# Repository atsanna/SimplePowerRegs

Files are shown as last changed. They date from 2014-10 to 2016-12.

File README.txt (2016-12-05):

This is the Simple Power series of switching regulators,
and its Open Source Hardware OSHW documentation.

They were designed in this order, making changes and improvements
along the way. pwrlnk.com has a blog with some discussion of the 
design process.

v1 
is 5V 3A output, with up to 30VDC input.
still useful for smaller loads.

v2 
changes the switcher part to 5 Amp output and adds a full-wave 
bridge at the input, up to 7-28VDC or 6-18VAC.

The same board supports two variations with a few parts changes:
1) 5Amp fixed 5VDC output.
2) 5Amp varible 1.2 ~ 15 VDC output.

v3 
is 5V 5A output, with 7-28VDC or 6-18VAC input.

v4 
is a refinement of v3, available at tindie.com

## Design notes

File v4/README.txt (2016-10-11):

v4:

This version is a refinement of v3, also fixed 5V with 2 USB charge ports. 

It has a 5.5mm/2.1mm barrel connector on the input, and pads for bare wires
up to 16 AWG on input and output.

The board is compatible with 1cmg.net, 48mm (1.89") square with 3.2mm (1/8") 
mounting holes on 40mm (1.575") centers, suitable for 4-40 or M3 screws.

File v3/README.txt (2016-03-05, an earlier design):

v3 was designed during the 1st Kickstarter campaign.

This version is 5V only, with 2 USB connectors.

The through hole manufacturing costs of the v2 full wave bridge 
part was troubling. So I made the bridge surface mount only by 
changing to 4 SMD schottky diodes. 

I also added a 26 V TVS diode to clip off any peaks in the input 
that get too close to the chip's 30 Volt absolute max rating.

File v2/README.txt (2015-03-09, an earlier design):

v2:
This is a one board, two products design with both 5 Volt and 
adjustable voltage output, up to 5 Amps. Only a few parts are 
different between the two models.

See http://pwrlnk.com/?q=node/6

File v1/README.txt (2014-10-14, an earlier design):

v1:
This is fixed 5V output up to 3 Amps. I used the design process 
in the TI data sheet, so my own value added here is in the 
board layout. The full ground plane acts as a heatsink, so no
external heat sink should be needed.

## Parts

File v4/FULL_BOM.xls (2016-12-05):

SMALL SYSTEMS LLC |  |  | MODEL 55
FIND | ID | Manufacturer | Mfg Part # | Description | Notes
1 | U1 | TI | TPS54531 | IC REG BUCK ADJ 5A 8SOPWRPAD | 3.5 ~ 28
2 | L1 | COOPER BUSSMAN | DR125-6R8-R | INDUCTOR SHIELD PWR 6.8UH SMD | 6.6A (8.7A sat)
3 | D1 | NXP | PMEG4050EP,115 | DIODE SCHOTTKY 40V 5A SOD128 | BRIDGE
 | D2 | NXP | PMEG4050EP,115 | DIODE SCHOTTKY 40V 5A SOD128 | BRIDGE
 | D3 | NXP | PMEG4050EP,115 | DIODE SCHOTTKY 40V 5A SOD128 | BRIDGE
 | D4 | NXP | PMEG4050EP,115 | DIODE SCHOTTKY 40V 5A SOD128 | BRIDGE
 | D6 | NXP | PMEG4050EP,115 | DIODE SCHOTTKY 40V 5A SOD128 | CATCH
4 | D5 | BOURNS | SMAJ26A | TVS 26 VOLTS | OVER-VOLT
5 | D7 | LITE-ON | LTST-C191KGKT | LED GREEN CLEAR 0603 SMD | PWR-ON
6 | C1 | Samsung | CL32B106KLJNNNE | CAP CER 10UF 35V 10% X7R 1210 | IN
 | C2 | Samsung | CL32B106KLJNNNE | CAP CER 10UF 35V 10% X7R 1210 | IN
7 | C3 | KEMET | C0805C103K5RACTU | CAP CER 10000PF 50V 10% X7R 0805 | IN
 | C4 | KEMET | C0805C103K5RACTU | CAP CER 10000PF 50V 10% X7R 0805 | BOOT
 | C7 | KEMET | C0805C103K5RACTU | CAP CER 10000PF 50V 10% X7R 0805 | SLOW
8 | C5 | AVX | 06035C220JAT2A | CAP CER 22PF 50V 5% X7R 0603 | COMP
9 | C6 | KEMET | C0805C222J5RACTU | CAP CER 2200PF 50V X7R 0805 | COMP
10 | C8 | Murata | GRM31CR61A476KE15L | CAP CER 47UF 10V 10% X5R 1206 | OUT
 | C9 | Murata | GRM31CR61A476KE15L | CAP CER 47UF 10V 10% X5R 1206 | OUT
11 | R1 | BOURNS | CR0603-JW-393GLF | RES SMD 39K OHM 5% 1/10W 0603 | COMP
12 | R2 | BOURNS | CR0603-FX-1202ELF | RES SMD 12K OHM 1% 1/10W 0603 | DIV-HI-5
13 | R3 | BOURNS | CR0603-FX-2211ELF | RES SMD 2.21K OHM 1% 1/10W 0603 | DIV-LO-5
15 | R4 | BOURNS | CR0603-JW-331GLF | RES SMD 330 OHM 5% 1/10W 0603 | PWR-ON
14 | R5 | BOURNS | CR0603-JW-101ELF | RES SMD 100 OHM 5% 1/10W 0603 | USB
 | R6 | BOURNS | CR0603-JW-101ELF | RES SMD 100 OHM 5% 1/10W 0603 | USB
NO-LOAD – optional connectors
16 | J1 | CUI | PJ-102AH | JACK MALE 2.1mm ID, 5.5mm OD | 5 Amp Hi Current
17 | J4 | FCI | 87520-0010BLF | CONN RCPT USB TYPE A R/A PCB | OUT
 | J5 | FCI | 87520-0010BLF | CONN RCPT USB TYPE A R/A PCB | OUT
18 | J2 | ON SHORE TECH | OSTTC022162 | TERM BLOCK 5.08MM VERT 2POS PCB | IN
 | J3 | ON SHORE TECH | OSTTC022162 | TERM BLOCK 5.08MM VERT 2POS PCB | OUT

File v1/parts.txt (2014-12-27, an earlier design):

DIGIKEY PART NUMBER	DESCRIPTION
-------------------	-----------

LM2676SX-5.0/NOPBCT-ND	IC REG BUCK 5V 3A TO263-7

513-1528-1-ND		INDUCTOR SHIELD PWR 33UH SMD
			COILTRONICS DR125-330-R

SK34A-LTPMSCT-ND	DIODE SCHOTTKY 40V 3A DO214AC
			MICRO COMMERCIAL SK34A-LTP

ED2609-ND		TERM BLOCK 5.08MM VERT 2POS PCB
			ON SHORE TECHNOLOGY OSTTC022162

399-3775-1-ND	C1	CAP TANT 15UF 35V 10% 2917
		C2	KEMET T.491.D.156.K.035.A.T

478-5231-1-ND	C3	CAP TANT 100UF 10V 20% 1210
		C4	AVX TPS.B.107.M.010.R.0400

399-1158-1-ND	C5	CAP CER 10000PF 50V 10% X7R 0805
							
609-1045-ND		USB 87520-0010BLF 2Amp

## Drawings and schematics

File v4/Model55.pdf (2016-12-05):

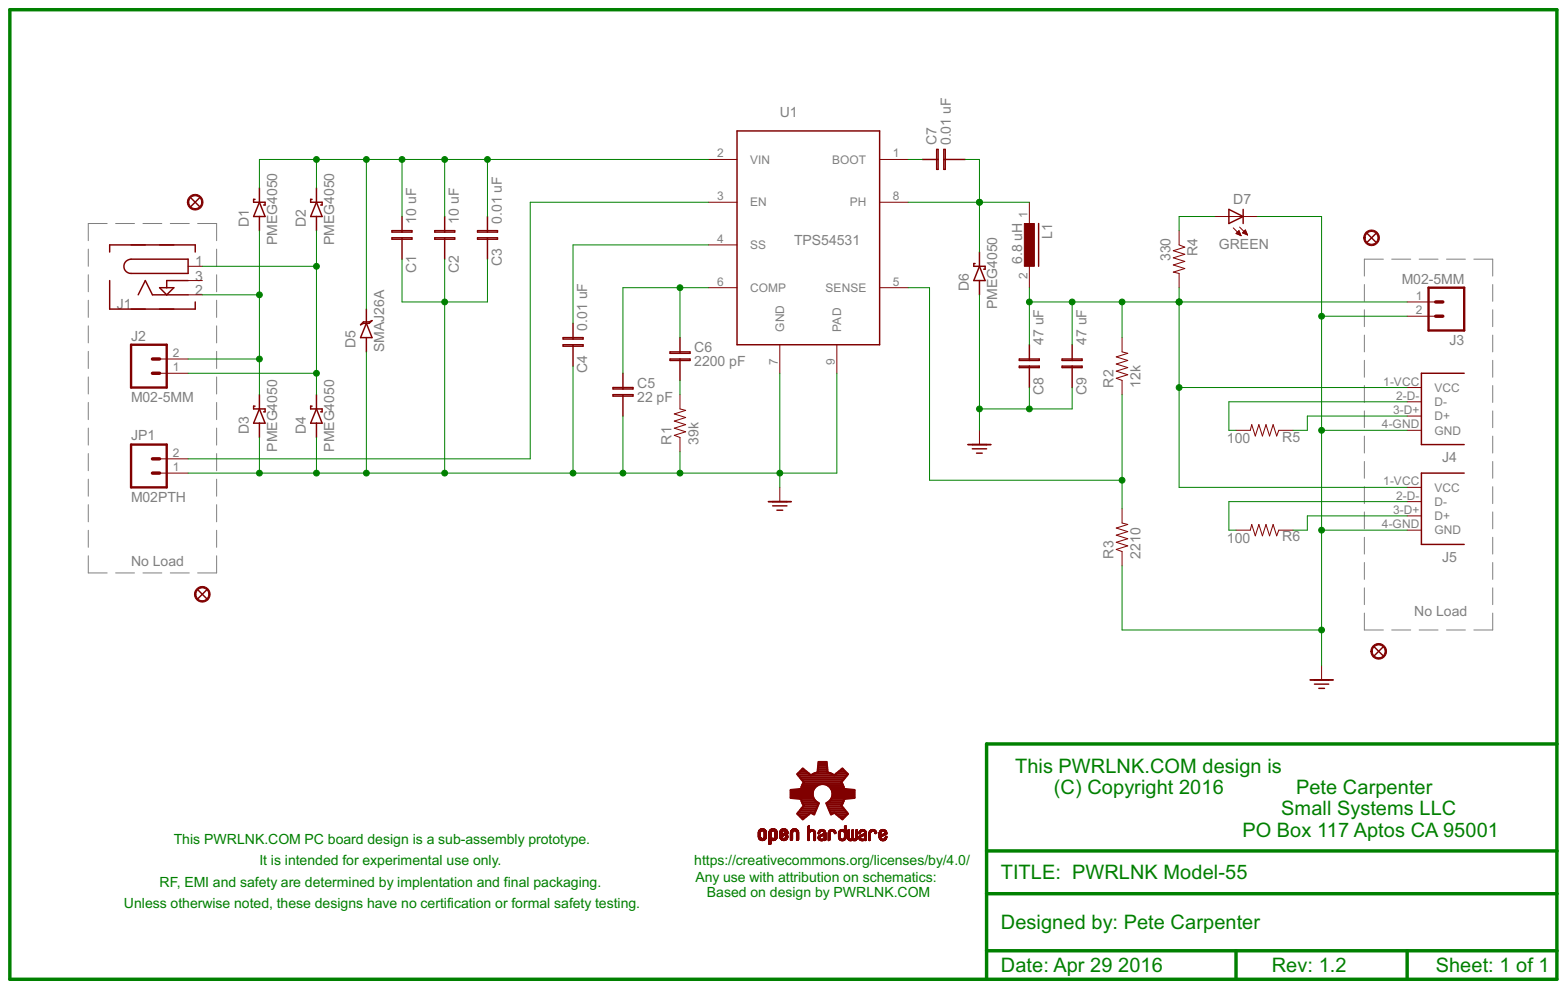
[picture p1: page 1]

This PWRLNK.COM design is

Small Systems LLC
PO Box 117 Aptos CA 95001

This PWRLNK.COM PC board design is a sub-assembly prototype. RF, EMI and safety are determined by implentation and final packaging. Unless otherwise noted, these designs have no certification or formal safety testing.

Any use with attribution on schematics: Based on design by PWRLNK.COM

Designed by: Pete Carpenter

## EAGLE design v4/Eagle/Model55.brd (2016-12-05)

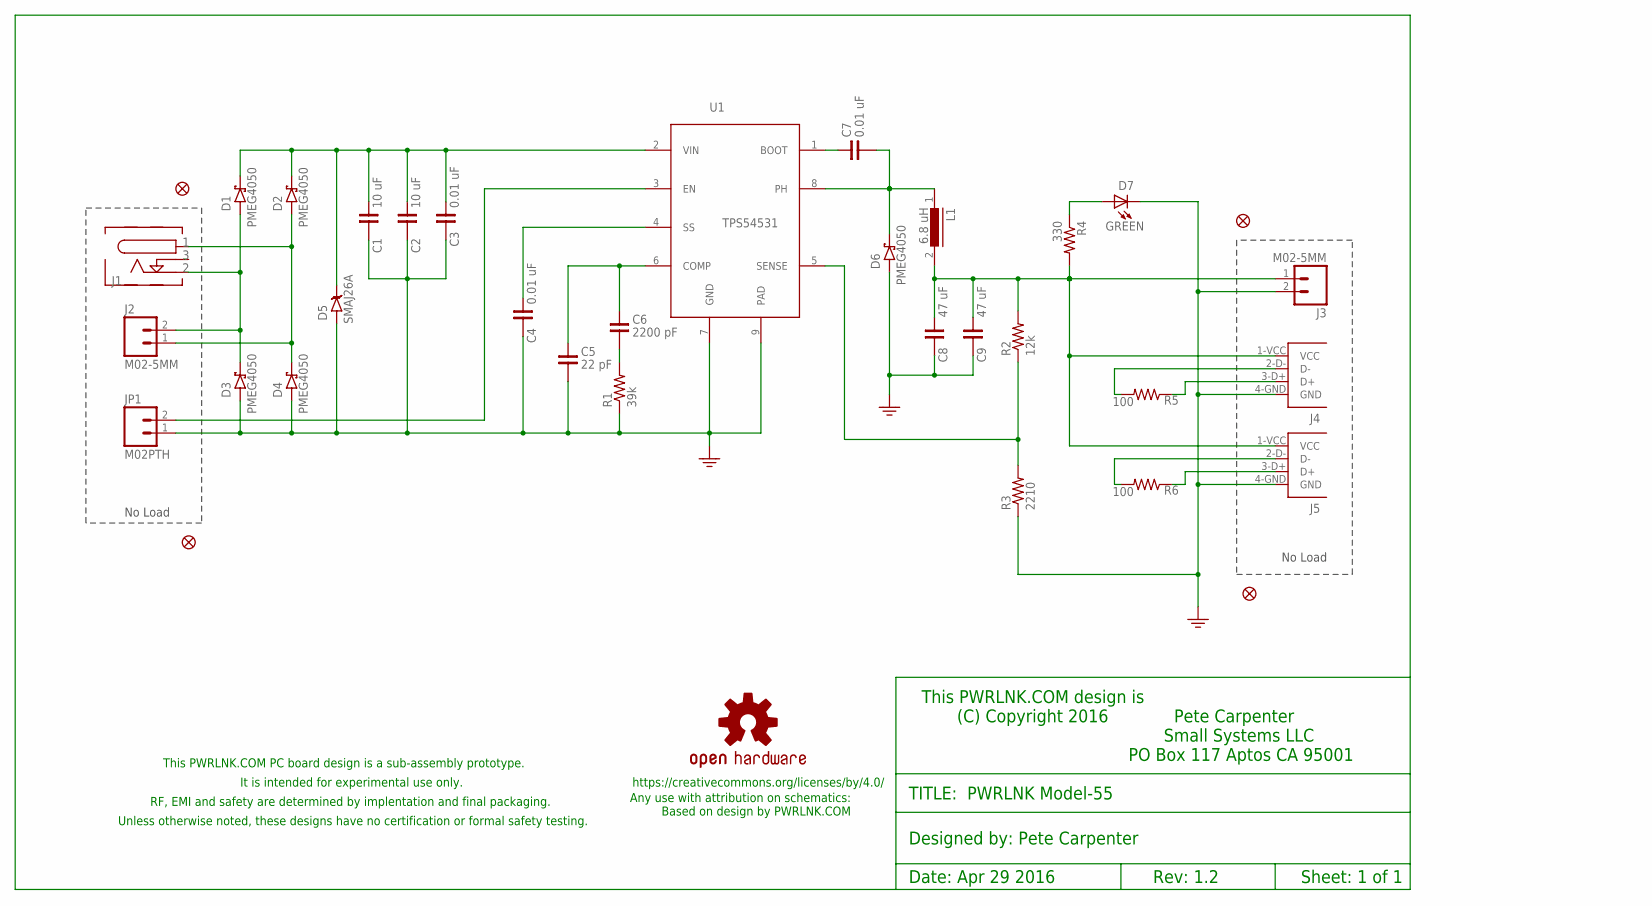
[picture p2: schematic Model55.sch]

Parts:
C1, C2: 10 uF; 1210
C3, C4, C7: 0.01 uF; 0805
C5: 22 pF; 0603
C6: 2200 pF; 0805
C8, C9: 47 uF; C1206
D1, D2, D3, D4, D6: PMEG4050EP; SOD128
D5: SMAJ26A; DO214BA
D7: GREEN; LED-0603
FID1, FID2, FID3, FID4: FIDUCIAL1X2; FIDUCIAL-1X2
J1: PJ-102AH
J2, J3: M02-5MM; SCREWTERMINAL-5MM-2
J4, J5: 87520; 87520-USB-A-FEMALE
JP1: M02PTH; 1X02
L1: 6.8 uH; DR125
LOGO1: OSHW-LOGOL; OSHW-LOGO-L
R1: 39k; 0603-RES
R2: 12k; 0603-RES
R3: 2210; 0603-RES
R4: 330; 0603-RES
R5, R6: 100; 0603-RES
U1: TPS54531; SOIC127P600X170-9N

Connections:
5V: C8.1, C9.1, J3.1, J4.1-VCC (VCC), J5.1-VCC (VCC), L1.2, R2.2, R4.2
AC1: D1.P$1A, D3.P$2C, J1.P$2 (2), J2.2
AC2: D2.P$1A, D4.P$2C, J1.P$1 (1), J2.1
BOOT: C7.1, U1.1 (BOOT)
COMP: C5.1, C6.1, U1.6 (COMP)
D+: J5.3-D+ (D+), R6.1
D+1: J4.3-D+ (D+), R5.1
D-: J5.2-D- (D-), R6.2
D-1: J4.2-D- (D-), R5.2
ENABLE: JP1.2, U1.3 (EN)
GND: C1.2, C2.2, C3.2, C4.2, C5.2, C8.2, C9.2, D3.P$1A, D4.P$1A, D5.A (P$1A), D6.P$1A, D7.C, J3.2, J4.4-GND (GND), J5.4-GND (GND), JP1.1, R1.1, R3.1, U1.7 (GND), U1.9 (PAD)
unnamed: C6.2, R1.2
PWRON: D7.A, R4.1
SENSE: R2.1, R3.2, U1.5 (SENSE)
SLOW: C4.1, U1.4 (SS)
VIN: C1.1, C2.1, C3.1, D1.P$2C, D2.P$2C, D5.C (P$2C), U1.2 (VIN)
VSW: C7.2, D6.P$2C, L1.1, U1.8 (PH)

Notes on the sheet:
No Load
Designed by: Pete Carpenter
This PWRLNK.COM design is (C) Copyright 2016 Pete Carpenter Small Systems LLC PO Box 117 Aptos CA 95001
TITLE: PWRLNK Model-55
Sheet: 1 of 1
Date: Apr 29 2016
Rev: 1.2
This PWRLNK.COM PC board design is a sub-assembly prototype.
RF, EMI and safety are determined by implentation and final packaging.
Unless otherwise noted, these designs have no certification or formal safety testing.
It is intended for experimental use only.
https://creativecommons.org/licenses/by/4.0/
Any use with attribution on schematics: Based on design by PWRLNK.COM

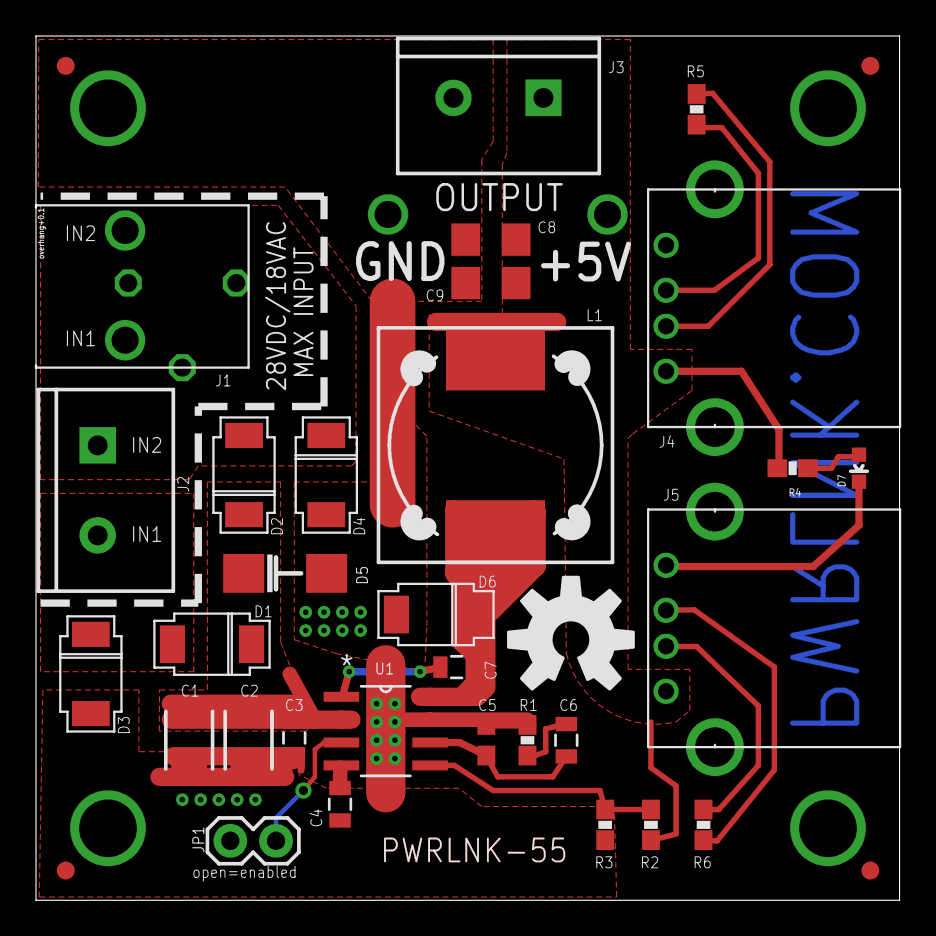
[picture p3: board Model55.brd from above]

Board: 2 copper layers, 48.0 x 48.0 mm, 35 parts (0 on the bottom side), 17 nets.

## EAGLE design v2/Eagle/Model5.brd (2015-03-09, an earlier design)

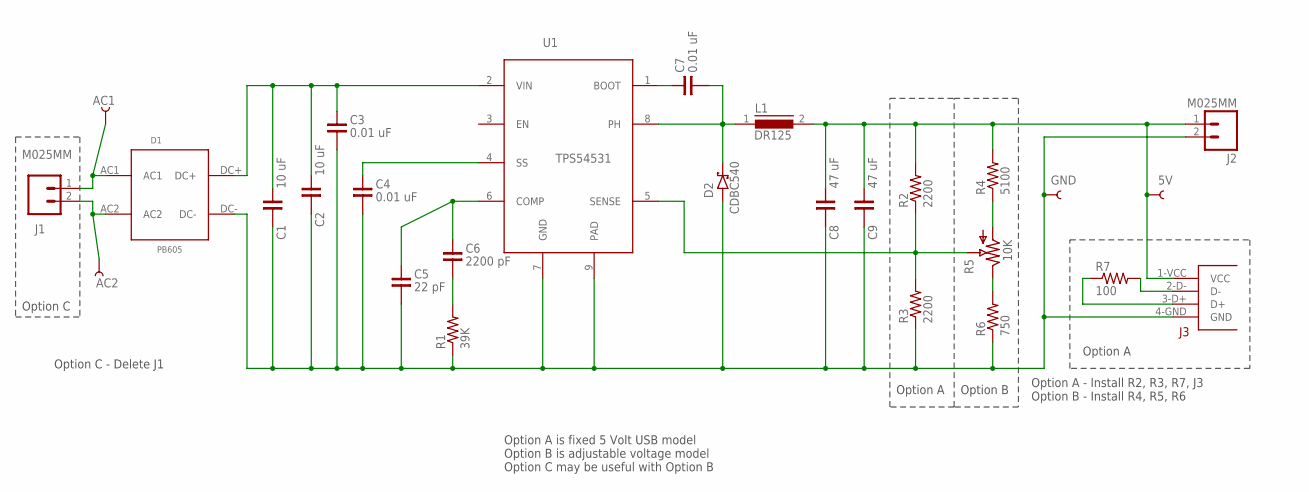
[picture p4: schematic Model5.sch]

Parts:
5V: TEST-POINT3; PAD.03X.03
AC1, AC2: TEST-POINT3; PAD.03X.03
C1, C2: 10 uF; 1210
C3, C4, C7: 0.01 uF; 0805
C5: 22 pF; 0805
C6: 2200 pF; 0805
C8, C9: 47 uF; C1206
D1: PB605; QUAD4PIN
D2: CDBC540; DO214AB
GND: TEST-POINT3; PAD.03X.03
J1, J2: M025MM; SCREWTERMINAL-5MM-2
JP3: 87520-USB-A-FEMALE
L1: DR125
R1: 39K; R0805
R2, R3: 2200; R0805
R4: 5100; R0805
R5: 3214J
R6: 750; R0805
R7: 100; R0805
U1: TPS54531; SOIC127P600X170-9N

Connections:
5V: 5V.P$1, C8.1, C9.1, J2.1, JP3.1-VCC (VCC), L1.2, R2.2, R4.2
AC1: AC1.P$1, D1.AC1, J1.1
AC2: AC2.P$1, D1.AC2, J1.2
BOOT: C7.1, U1.1 (BOOT)
COMP: C5.1, C6.1, U1.6 (COMP)
D+: JP3.3-D+ (D+), R7.1
D-: JP3.2-D- (D-), R7.2
GND: C1.2, C2.2, C3.2, C4.2, C5.2, C8.2, C9.2, D1.DC-, D2.ANODE, GND.P$1, J2.2, JP3.4-GND (GND), R1.1, R3.1, R6.1, U1.7 (GND), U1.9 (PAD)
unnamed: C6.2, R1.2
unnamed: R4.1, R5.P$1 (1)
unnamed: R5.P$3 (3), R6.2
SENSE: R2.1, R3.2, R5.P$2 (2), U1.5 (SENSE)
SLOW: C4.1, U1.4 (SS)
VIN: C1.1, C2.1, C3.1, D1.DC+, U1.2 (VIN)
VSW: C7.2, D2.CATHODE, L1.1, U1.8 (PH)

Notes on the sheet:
Option A - Install R2, R3, R7, J3 Option B - Install R4, R5, R6
Option A
Option B
Option C
Option C - Delete J1
Option A is fixed 5 Volt USB model Option B is adjustable voltage model Option C may be useful with Option B

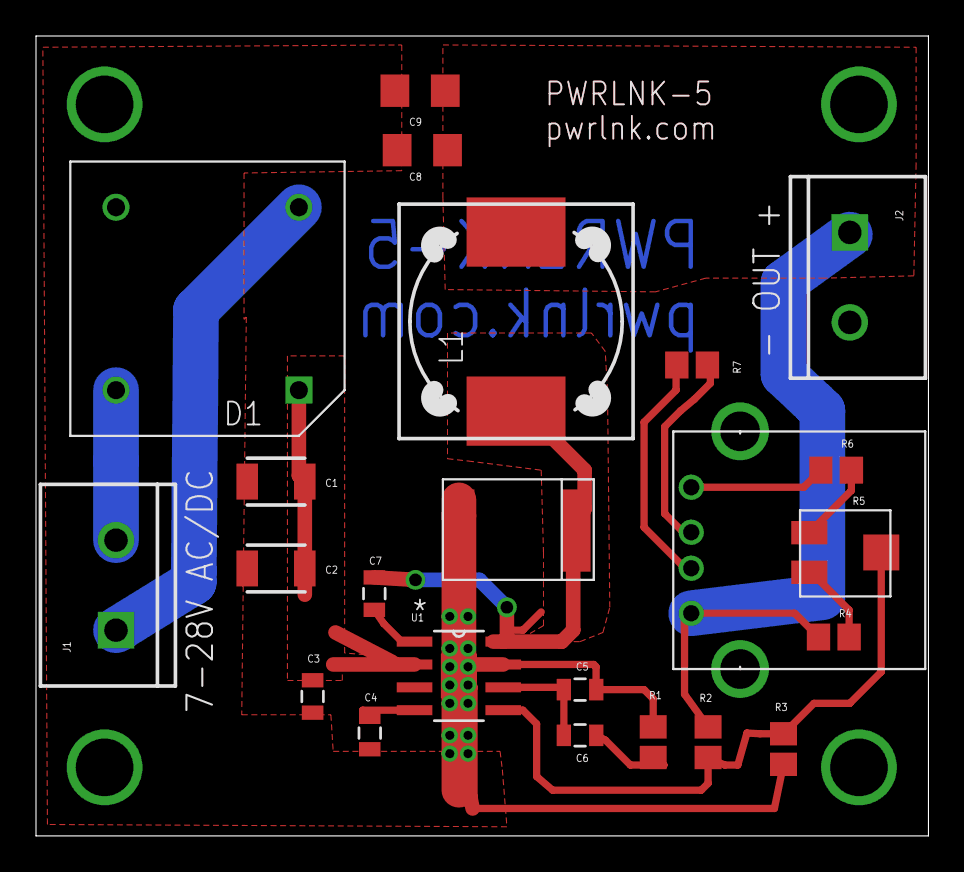
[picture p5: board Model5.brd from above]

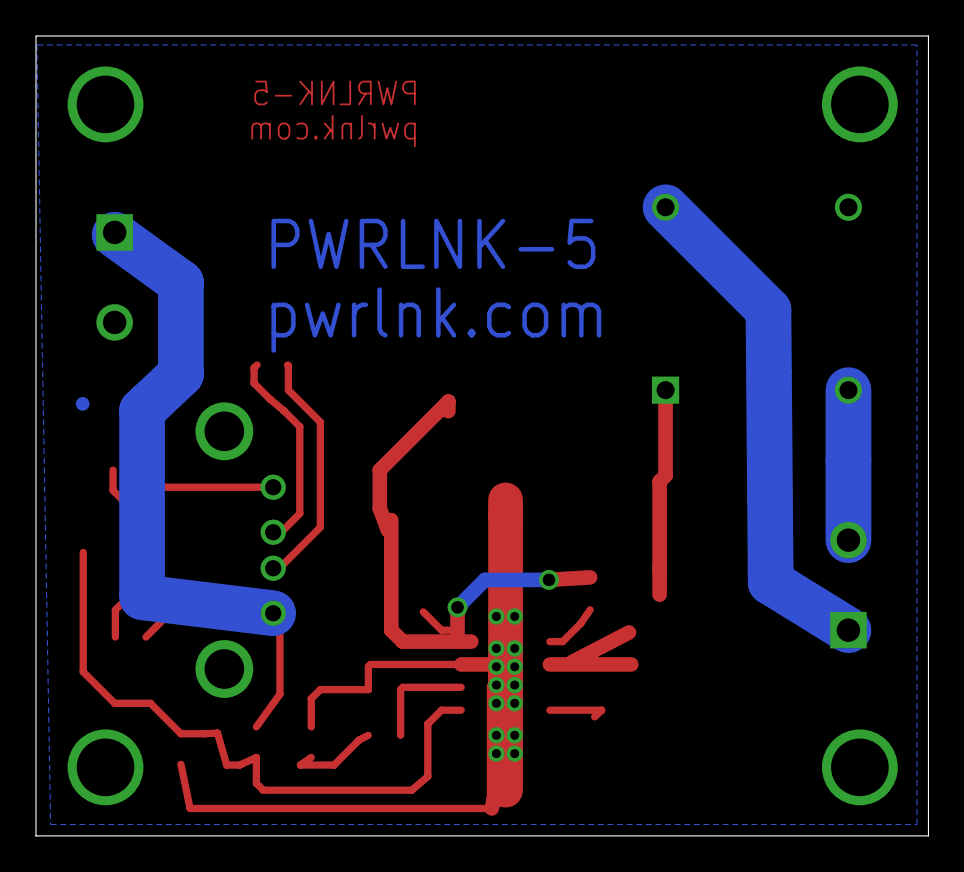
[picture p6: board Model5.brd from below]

Board: 2 copper layers, 49.6 x 44.4 mm, 27 parts (4 on the bottom side), 15 nets.

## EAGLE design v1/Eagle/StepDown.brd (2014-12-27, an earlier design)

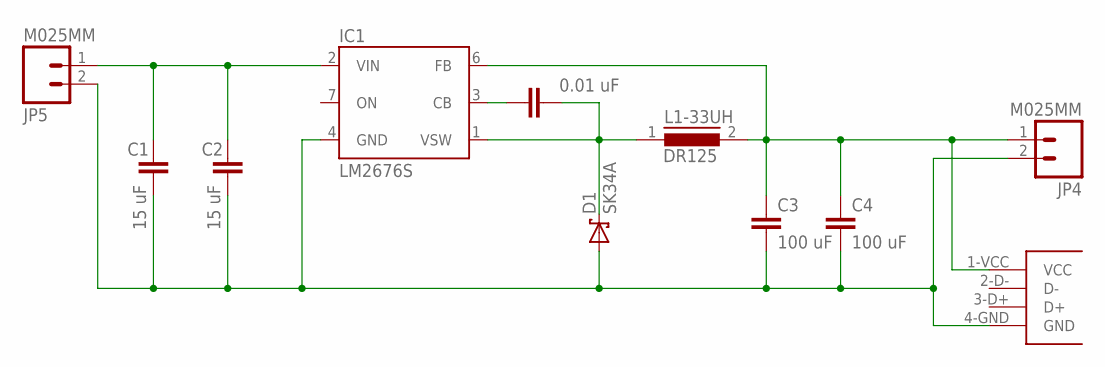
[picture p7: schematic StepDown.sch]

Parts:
C1, C2: 15 uF; C1210
C3, C4: 100 uF; C1210
C6: 0.01 uF; 0805
D1: SK34A; DO214AA
IC1: LM2676S; TO263-7
JP4, JP5: M025MM; SCREWTERMINAL-5MM-2
L1-33UH: DR125
U$1: 87520-USB-A-FEMALE

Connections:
5V: C3.1, C4.1, IC1.6 (FB), JP4.1, L1-33UH.2, U$1.1-VCC (VCC)
CB: C6.1, IC1.3 (CB)
GND: C1.2, C2.2, C3.2, C4.2, D1.A, IC1.4 (GND), JP4.2, JP5.2, U$1.4-GND (GND)
VIN: C1.1, C2.1, IC1.2 (VIN), JP5.1
VSW: C6.2, D1.C, IC1.1 (VSW), L1-33UH.1

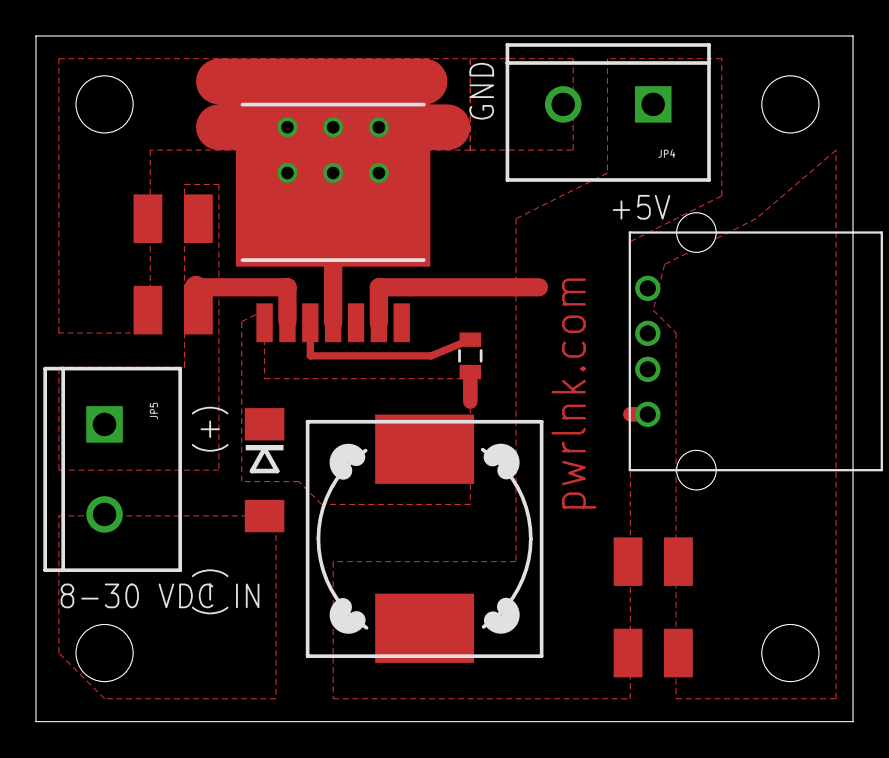
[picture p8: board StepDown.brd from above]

Board: 2 copper layers, 45.4 x 38.1 mm, 11 parts (0 on the bottom side), 5 nets.

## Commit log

2014-10-14 SimplePower setup
    READMEs for top and individual board directories.
2014-12-27 Eagle files, parts list, picture
    [StepDown.brd, StepDown.sch]
2015-03-09 Update v2 details
    added eagle files, some pictures, parts list
    [Model5.brd, Model5.sch, model5.ods]
2016-03-05 version 3
    5 Volts only, with surface mount bridge and TVS diode.
    [Model52.brd, Model52.sch]
2016-12-05 Added v4
    This is the release of version 4.
    [FULL_BOM.xls, Model55.brd, Model55.sch]

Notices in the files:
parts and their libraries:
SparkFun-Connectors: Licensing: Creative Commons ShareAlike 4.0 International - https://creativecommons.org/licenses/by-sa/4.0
